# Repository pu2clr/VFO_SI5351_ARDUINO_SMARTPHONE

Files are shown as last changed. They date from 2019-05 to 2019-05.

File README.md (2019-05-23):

# VFO and BFO using Arduino with Si5351 controlled by SmartPhone

By PU2CLR - Ricardo Lima Caratti  - April, 2019

## Table of contents

1. [Introduction](https://github.com/pu2clr/VFO_SI5351_ARDUINO_SMARTPHONE#introduction)
2. [VFO and BFO Interface](https://github.com/pu2clr/VFO_SI5351_ARDUINO_SMARTPHONE#vfo-and-bfo-interface)
3. [Schematic used with Arduino Atmega328 (UNO, Pro Mini, Nano etc)](https://github.com/pu2clr/VFO_SI5351_ARDUINO_SMARTPHONE#schematic---arduino-atmega328-uno-pro-mini-nano-etc)
4. [Arduino Sketch](https://github.com/pu2clr/VFO_SI5351_ARDUINO_SMARTPHONE#arduino-sketch)
   1. [Band Table](https://github.com/pu2clr/VFO_SI5351_ARDUINO_SMARTPHONE#band-table) 
   2. [Step Table](https://github.com/pu2clr/VFO_SI5351_ARDUINO_SMARTPHONE#step-table)
   3. [Callback Functions](https://github.com/pu2clr/VFO_SI5351_ARDUINO_SMARTPHONE#callback-functions)
5. [Mobile Application](https://github.com/pu2clr/VFO_SI5351_ARDUINO_SMARTPHONE#mobile-application)
6. [Videos](https://github.com/pu2clr/VFO_SI5351_ARDUINO_SMARTPHONE#videos)

## Introduction

This project implements a VFO and BFO  using an Arduino with Si5351 signal generator. You can controll the VFO using an encoder and also a SmartPhone via a mobile application developed here for this purpose. 

The heart of this VFO is the component Si5351. It is an I2C configurable clock generator that is very appropriate for receivers and transceivers projects in amateur radio applications. It has three outputs that you can get three distinct frequencies at the same time. A great feature of the Si5351A is the possibility of using it with a microcontroller or platform like Arduino, PIC family and others. See more on [Silicon Labs documentation](https://www.silabs.com/documents/public/data-sheets/Si5351-B.pdf).

 This project uses two outputs of the Si5351.  The VFO  uses the output 0 (CLK0) and can oscillate from 100KHz to 160MHz. The BFO uses the output 1 (CLK1) of Si5351 and it was configured to oscillate from 452KHz to 458KHz (you can modigy the BFO range to any other from 8KHz to 160MHz).  

 The Arduino sketch was projected to allow the user modify easly the band, range and step configurations.
 See Arduino Sketch below. 

## VFO and BFO interface

The user can control the VFO and BFO by using three buttons (bands, steps and VFO / BFO switch) and an encoder. The user can also connect this VFO with an iOS or Android device and control it remotelly.  The Dial was implemented with the OLED Display 128 x 64 Pixels White 0.96 Inch I2C. 

### Display Layout

| Layout |  Layout |
| --- |  --- |
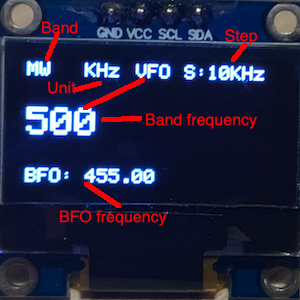
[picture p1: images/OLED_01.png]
Display photo 1
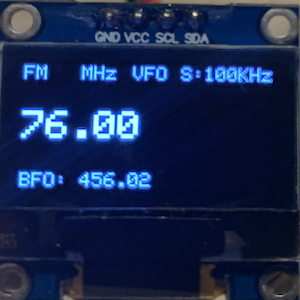
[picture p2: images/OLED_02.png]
Displau photo 2
| |  |
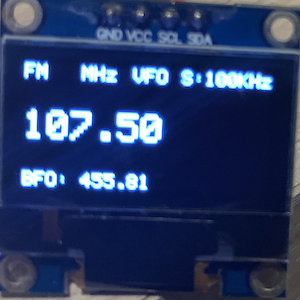
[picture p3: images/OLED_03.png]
Display photo 3
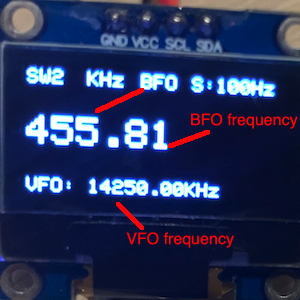
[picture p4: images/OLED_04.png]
Displau photo 4
| |  |

The display layout can be modified easily by changing the __DialDisplay() function__ on Arduino sketch. 

### Simple Smartphone Layout

| iPhone Application | Android Application  | 
| --- | --- |
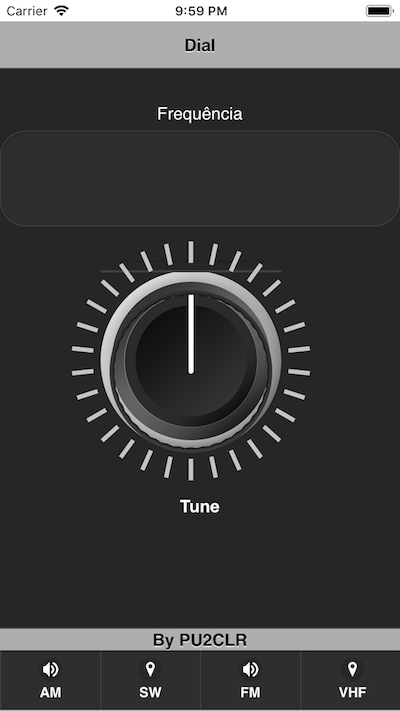
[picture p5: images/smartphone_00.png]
Smartphone Layout - iPhone
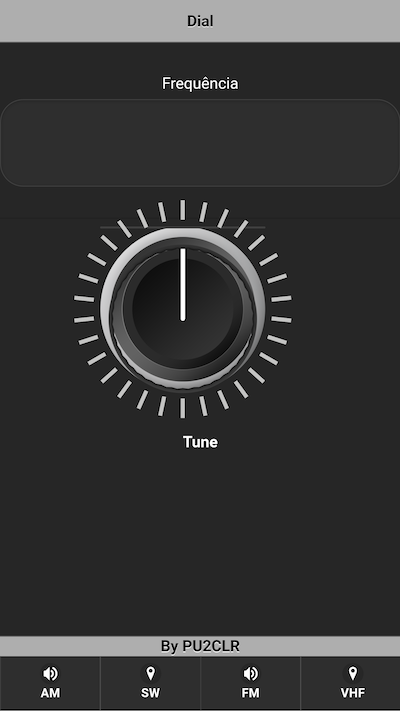
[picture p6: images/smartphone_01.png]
Smartphone Layout - iPhone
|  |  | 
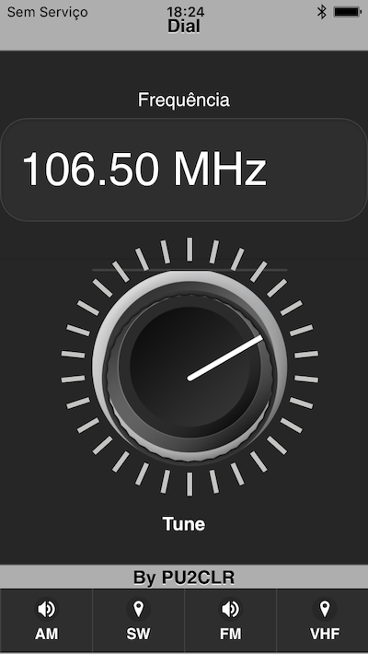
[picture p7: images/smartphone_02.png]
Smartphone Layout - iPhone
|  | - | 

See more detail about the [Mobile Application](https://github.com/pu2clr/VFO_SI5351_ARDUINO_SMARTPHONE#mobile-application) below.

## Schematic - Arduino Atmega328 (UNO, Pro Mini, Nano etc)

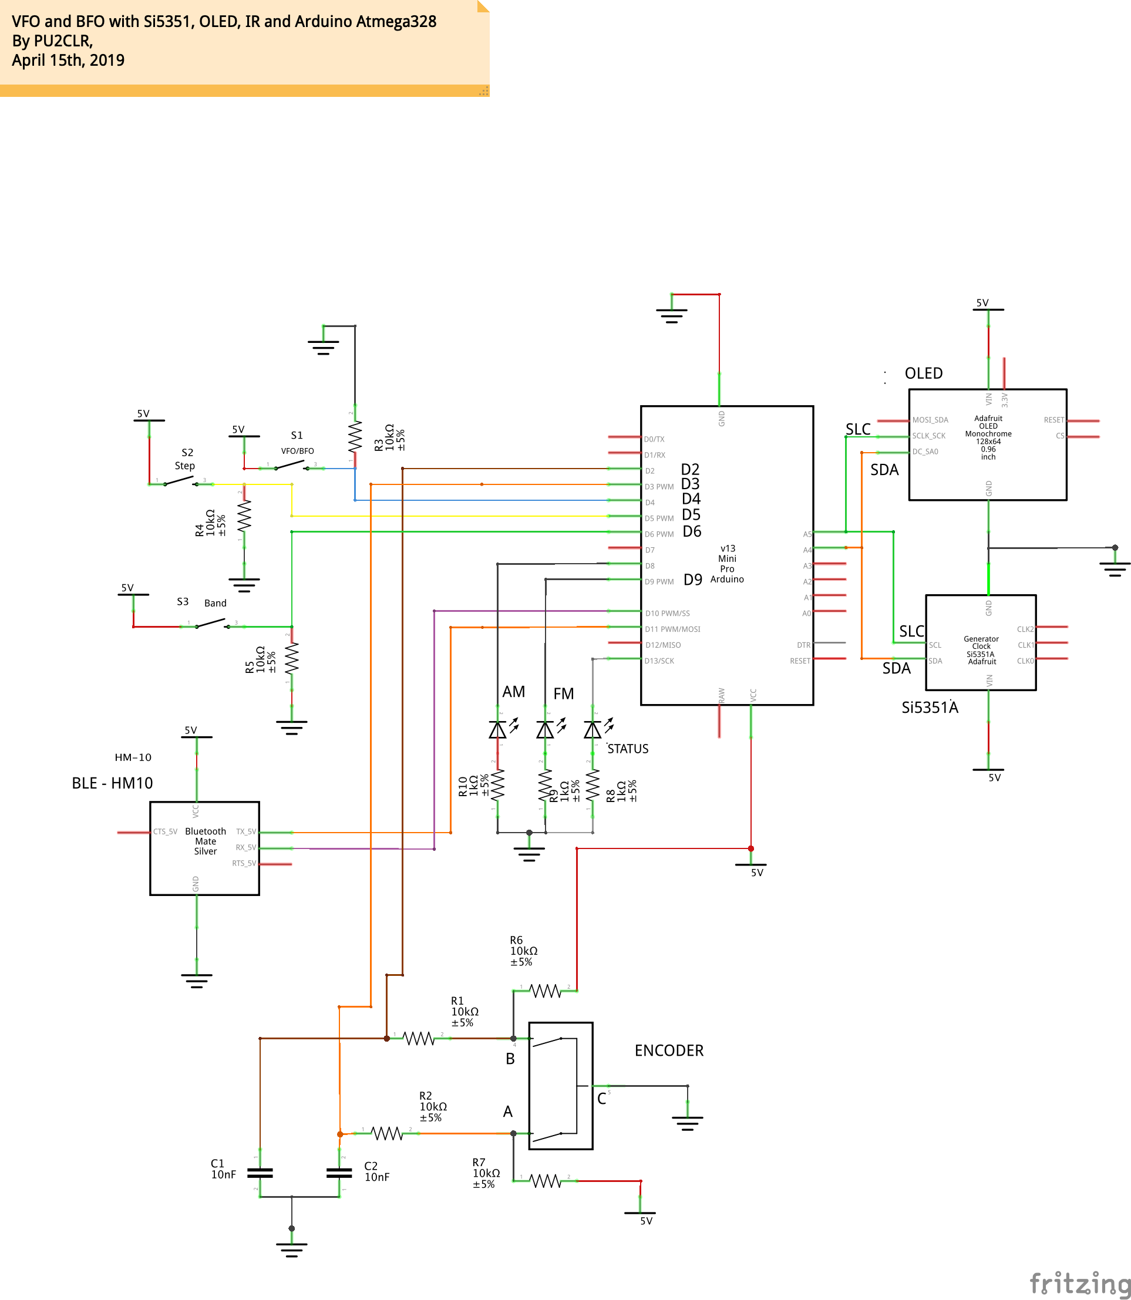
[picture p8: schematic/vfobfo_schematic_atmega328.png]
Schematic used with Arduino Atmega328


## Arduino Sketch 

The VFO and BFO project cen be easily modified to adapt it better to your needs. 
The main feature of the Sketch is the table of band. You can modify the amount of bands and ranges. The band information is shown below. 
 
| Band Information | Desription | 
| --- | --- |
| __Band name__ | Band name that will show on display. |
| __Initial Freq.__ |  Lowest band frequency (1/100 Hz). |
| __Final Freq.__ | highest frequency band (1/100 Hz). |
| __Last Freq.__ | Store the current frequency. Useful when the user switches the band and get back to it later (it starts with minFreq value). |
| __offset__ | Consider an IF offset.  The VFO shows on the display the real frequency of the station and makes the signal generator to oscillate considering the IF used by the radio design (1/100 Hz). |
| __Freq Unit__ | Frequency unit that will be shown on the display for the current band. |
| __Divider__ | Divider used to reduce the number of digits in the display. |
| __decimals__ | number of decimal places (precision). |
| __Initial Step Index__ | Lowest step index used for the band (see Step table). |
| __Final Step Index__ | Highest step index used for the band (see Step table). | 
| __Last Step Index__ | Default step index or last step index used for the band (see Step table). Useful when the user gets back to a band. | 
| __callback function__ | Pointer to the function that handles something when the band is selected. Can be NULL if there is nothing to do.  |

The implementation of the band information is shown below.  An array of band structure information is implemmented 

```cpp
// Structure for Bands database
typedef struct
{
  char *name;
  uint64_t minFreq;       // Min. frequency value for the band (unit 0.01Hz)
  uint64_t maxFreq;       // Max. frequency value for the band (unit 0.01Hz)
  uint64_t lastFreq;      // Store the current frequency before change to other band (starts with minFreq value)
  long long offset;
  char *unitFreq;         // MHz or KHz
  float divider;          // value that will be the divider of current clock (just to present on display)
  short decimals;         // number of digits after the comma
  short initialStepIndex; // Index to the initial step of incrementing
  short finalStepIndex;   // Index to the final step of incrementing
  short lastStepIndex;    // Index to the last step used (initial index value same index defult)
  void (*doSmth)(void);   // pointer to the function that will handle specific things for the band immediately after the band is selected
 } Band;
```

The code below implements the band table (array) of the VFO for a hypothetical radio. 
The hypothetical radio used as an example here has 10 bands. Each band has a frequency range, a default frequency, an IF offset, a unit used for the band (MHz or KHz), a divider to convert the unit (from 1/100Hz to KHz or MHz), decimal digits used for the band (precision), minimum step used for the band (index), maximum step used for the band, default step index and a pointer to function that will be executed when the band is selected (or NULL if no action is needed).  The values amBroadcast, fmBroadcast and defultFinishBand are pointers to functions that will execute some specific actions for the band. When the value is NULL, no action will be executed.  You might need change these values depending on your radio design. 

```cpp
// Band database. You can change the band ranges if you need.
// The unit of frequency here is 0.01Hz (1/100 Hz). See Etherkit Library at https://github.com/etherkit/Si5351Arduino
 Band band[] = {
     {"MW  ", 50000000LLU, 170000000LLU, 50000000LLU, 45500000LU, "KHz", 100000.0f, 0, 3, 6, 5, amBroadcast},
     {"SW1 ", 170000000LLU, 1000000000LLU, 170000000LLU, 45500000LU, "KHz", 100000.0f, 2, 1, 6, 3, amBroadcast},
     {"SW2 ", 1000000000LLU, 2000000000LLU, 1000000000LLU, 45500000LU, "KHz", 100000.0f, 2, 1, 6, 3, amBroadcast},
     {"SW3 ", 2000000000LLU, 3000000000LLU, 2000000000LLU, 45500000LU, "KHz", 100000.0f, 2, 1, 6, 3, amBroadcast},
     {"VHF1", 3000000000LLU, 7600000000LLU, 3000000000LLU, 45500000LU, "KHz", 100000.0f, 2, 1, 7, 3, defultFinishBand},
     {"FM  ", 8600000000LLU, 10800000000LLU, 8600000000LLU, 1075000000LLU, "MHz", 100000000.0f, 2, 5, 8, 7, fmBroadcast},
     {"AIR ", 10800000000LLU, 13700000000LLU, 10800000000LLU, 1070000000LLU, "MHz", 100000000.0f, 3, 2, 8, 5, NULL},
     {"VHF2", 13700000000LLU, 14400000000LLU, 13700000000LLU, 1070000000LLU, "MHz", 100000000.0f, 3, 2, 8, 5, defultFinishBand},
     {"2M  ", 14400000000LLU, 15000000000LLU, 14400000000LLU, 1070000000LLU, "MHz", 100000000.0f, 3, 2, 8, 5, defultFinishBand},
     {"VFH3", 15000000000LLU, 16000000000LLU, 15000000000LLU, 1070000000LLU, "MHz", 100000000.0f, 3, 2, 8, 5, defultFinishBand}};
 // Calculate the last element position (index) of the array band
```

### Band Table 

The table of bands implemented above for the hypothetical radio can be seen below. The values of Initial Step Index, Final Step Index and Default/Last Step index can be got from the Step table.  

| Band name | Initial Freq.  | Final Freq. | Last Freq. | offset | Freq Unit | Divider | Dec. | Initial Step Index | Final Step Index | Default / Last Step index | Action Function |
| --- | --- | --- | --- | --- | ---| --- |--- | --- | --- | ---| ---|
| MW | 50000000 | 170000000 | 50000000 | 45500000 |  KHz | 100000 | 2 | 3 | 6 | 5 | amBroadcast |
| SW1  | 170000000 | 1000000000 | 170000000 | 45500000  | KHz | 100000 | 2 | 2 | 6 | 3 | amBroadcast |
| SW2  | 1000000000 | 2000000000 | 1000000000 | 45500000  | KHz | 100000 | 2 | 2 | 6 | 3 | amBroadcast |
| SW3  | 2000000000 | 3000000000 | 2000000000 | 45500000  | KHz | 100000 | 2 | 2 | 6 | 3 | amBroadcast |
| VHF1 | 3000000000 | 7600000000 | 3000000000 | 45500000  | KHz | 100000 | 2 | 2 | 7 | 3 | defultFinishBand |
| FM | 7600000000 | 10800000000 | 7600000000 | 1075000000  | MHz |  100000000 | 1 | 6 | 8 | 7 | fmBroadcast |
| AIR  | 10800000000 | 13700000000 | 10800000000 | 1075000000  | MHz | 100000000 | 2 | 2 | 8 | 5 | NULL |
| VHF2 | 13700000000 | 14400000000 | 13700000000 | 1075000000  | MHz | 100000000 | 2 | 2 | 8 | 5 | defultFinishBand |
| 2M  | 14400000000 | 15000000000 | 14400000000 | 1075000000  | MHz | 100000000 | 2 | 2 | 8 | 5 | defultFinishBand |
| VFH3 | 15000000000 | 16000000000 | 15000000000 | 1075000000  | MHz| 100000000 | 2 | 2 | 8| 5 | defultFinishBand |

### Step Table 

Each band uses a subset of the table of steps. It will depend on the characteristics of the band. For example: usually, 5KHz and 10 KHz are more apropriated to MW band. Working on SW bands, you might want 1KHz, 5KHz and 10KHz. The step table is implemented by the code below.  

```cpp
// Struct for step database
typedef struct
{
  char *name; // step label: 50Hz, 100Hz, 500Hz, 1KHz, 5KHz, 10KHz and 500KHz
  long value; // Frequency value (unit 0.01Hz See documentation) to increment or decrement
} Step;
```

The code beloow implements an array of steps (Steps)

```cpp 
// Steps database. You can change the Steps and numbers of steps here if you need.
Step step[] = {
    {"10Hz  ", 1000},
    {"100Hz ", 10000},
    {"500Hz ", 50000},
    {"1KHz  ", 100000},
    {"5KHz  ", 500000},
    {"10KHz  ",1000000},
    {"50KHz ", 5000000},
    {"100KHz", 10000000},
    {"500KHz", 50000000}};
```

The table of steps implemented above  can be seen below.

| Step Index | Step name | Step Value (1/100 Hz) |
| --- | --- | --- |
| 0 | 10Hz | 1000 |
| 1 | 100Hz | 10000 |
| 2 | 500Hz | 50000 |
| 3 | 1KHz | 100000 |
| 4 | 5KHz | 500000 |
| 5 | 10KHz |  1000000 |
| 6 | 50KHz |  5000000 |
| 7 | 100KHz | 10000000 |
| 8 | 500KHz | 50000000 |

### Callback functions

This sketch uses callback functions to complement specific actions for a specific band. 
For example, you might need to turn a LED on, start a relay or set up a filter when you select a particular band.  If the device that will use this VFO/BFO has different behaviours for different band, you might want to use callback functions.  If you do not need to use this features, you can set this data (parameter) with NULL in table of bands. See Band table for more information. 

The code below shows the callback functions declaration

```cpp
// Callback functions declarations
// Depending on the selected band, you may want to perform specific actions
// The functions declared below will do something for AM and FM BAND. See implementation later.
// You can implement callback function for other bands
void amBroadcast();      // See implementation later.
void fmBroadcast();      // See implementation later.
void defultFinishBand(); // 
```

The callback functions above are referenced in band database (see table of bands -  array band[]) above.

```cpp
// Callback implementation

// Doing something spefict for MW band
void amBroadcast()
{
  digitalWrite(AM_LED, HIGH); // Turn ON the AM LED
  digitalWrite(FM_LED, LOW);
  // DO SOMETHING ELSE
}

// Doing something spefict for FM
void fmBroadcast()
{
  digitalWrite(AM_LED, LOW);
  digitalWrite(FM_LED, HIGH); // Turn ON the FM LED
  // DO SOMETHING ELSE
}

// Defaul action 
// It is another callback function that can be called when a specific band is selected 
void defultFinishBand()
{
  digitalWrite(FM_LED, LOW); // Turno the FM LED OFF
  digitalWrite(AM_LED, LOW); // Turno the AM LED OFF
  // DO SOMETHING ELSE  
}

```

The code below shows the use of callback function when the use changes the band

```cpp
// It is executed when a new band is selected.
void changeBand(short idxBand)
{
  // Save current status of the current band
  band[currentBand].lastStepIndex = currentStep;
  band[currentBand].lastFreq = vfoFreq;

  // Now change the current band  
  currentBand = idxBand;

  // Get back last information stored for this band.
  vfoFreq = band[idxBand].lastFreq;           
  currentStep = band[idxBand].lastStepIndex;

  // Call callback function if exist something to do for this band (current band)
  if (band[idxBand].doSmth != NULL)
    (band[idxBand].doSmth)();

  isFreqChanged = true;
}
```  

The complete Arduino Sketch can be seen [here](https://github.com/pu2clr/VFO_SI5351_ARDUINO_SMARTPHONE/tree/master/source)

## Mobile Application

The reduced length of the Oled display might limit some VFO functionalities.  The goal of this mobile application is improve the VFO control and visualization. 

### Bluetooth BLE (HM10 - HMSOft TineSine)

The Bluetooth 4.0 used here is the HM10 (TinySine). It is very similar to the famous HC-05. The photos below show the HM10 Bluetooth.
This kind of Bluetooth works well on iOs and Android based device.

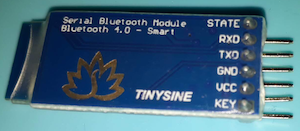
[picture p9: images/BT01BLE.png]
HM10 - HMSOft TineSine 01


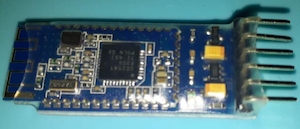
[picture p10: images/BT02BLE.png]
HM10 - HMSOft TineSine 02


#### HM10 Documentation

* [HM-10 Bluetooth 4 BLE Modules - Martyn Currey](http://www.martyncurrey.com/hm-10-bluetooth-4ble-modules/)
* [BLE CENTRAL - HM-10 BLE Module](http://blog.blecentral.com/2015/05/05/hm-10-peripheral/)

### Compile and deploy this mobile application

Please copy the project to a local folder and follow the steps bellow

You have to install [Android Studio](http://developer.android.com/sdk/index.html) on your computer to compile and deploy this application on your Android.

You have to install [Xcode](https://developer.apple.com/xcode/) on your Mac computer to compile and deploy this application on your iPhone or iPad.  

### Pairing your phone

You have to pair your Android phone with the HM10 Bluetooth Shield.

### Cordova 

This applications was build using the [Apache Cordova](https://cordova.apache.org/docs/en/latest/guide/overview/index.html). 
[Apache Cordova](https://cordova.apache.org/docs/en/latest/guide/overview/index.html) is an open-source tool to develop cross-platform mobile application. Click [here](https://cordova.apache.org/docs/en/latest/guide/overview/index.html) to see more about Apache Cordova.

### Install Cordova

    $ npm install cordova -g

### Install Platform and Plugin

    $ cordova platform add android
    $ cordova platform add ios
    $ cordova plugin add cordova-plugin-bluetooth-serial

#### cordova-plugin-bluetooth-serial information

* [Bluetooth Serial Plugin for PhoneGap](https://www.npmjs.com/package/cordova-plugin-bluetooth-serial)
* [Bluetooth Serial Plugin for PhoneGap - github](https://github.com/don/BluetoothSerial)

### Build and Deploy

Compile and run the application

    $ cordova run android --device

## Videos 

- [VFO and BFO project test with an inexpencive radio based on CD2003GP](https://youtu.be/_KgBc6vYWLg)
- [Testing the VFO with a CD2003GM HOMEBREW FM RECEIVER](https://youtu.be/JfgRjDK8LTE)
- [VFO and BFO remote control with iPhone via Bluetooth](https://youtu.be/7gBRUmsrCus)

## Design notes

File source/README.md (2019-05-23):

# Sorce content

By PU2CLR - Ricardo Lima Caratti  - April, 2019

| Folder name | Description | 
| --- | --- |
| si5351_vfo_ble_atmega328  | Arduino Sketch for Atmega328 (Uno, Nano, Mini etc) | 
| si5351_vfo_ble_atmega328X | Arduino Sketch for Atmega328 (Uno, Nano, Mini etc) with Ben Buxton Encoder implementation | 
| vfoMobileApplication | iOs and Android remote control implementation for the VFO |

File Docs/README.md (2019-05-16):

# Testando o VO e BFO em um rádio barato baseado no chip CD2003GP 

__Importante: Documentação ainda em construção__

Por PU2CLR - Ricardo
April, 2019

## Sumário

1. [Introdução](https://github.com/pu2clr/VFO_BFO_OLED_ARDUINO/tree/master/Experiments/VFO_RADIO_CD2003GP/Docs#introdução)
2. [Apresentação do Display](https://github.com/pu2clr/VFO_BFO_OLED_ARDUINO/tree/master/Experiments/VFO_RADIO_CD2003GP/Docs#apresentação-do-display)
3. [Esquema para Arduino baseado no Atmega328 (UNO, Pro Mini, Nano etc)](https://github.com/pu2clr/VFO_BFO_OLED_ARDUINO/tree/master/Experiments/VFO_RADIO_CD2003GP/Docs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)
4. [Esquema para Arduino baseado ATmega32U4 (Micro)](https://github.com/pu2clr/VFO_BFO_OLED_ARDUINO/tree/master/Experiments/VFO_RADIO_CD2003GP/Docs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)
5. [O Rádio baseado no CD2003GP utilizado no teste](https://github.com/pu2clr/VFO_BFO_OLED_ARDUINO/tree/master/Experiments/VFO_RADIO_CD2003GP/Docs#o-rádio-baseado-no-cd2003gp-utilizado-no-teste)
   1. [Diagrama de Bloco do CD2003GP](https://github.com/pu2clr/VFO_BFO_OLED_ARDUINO/tree/master/Experiments/VFO_RADIO_CD2003GP/Docs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)
   2. [Circúito de Aplicação](https://github.com/pu2clr/VFO_BFO_OLED_ARDUINO/tree/master/Experiments/VFO_RADIO_CD2003GP/Docs#circúito-de-aplicação)
   3. [Foto do Rádio](https://github.com/pu2clr/VFO_BFO_OLED_ARDUINO/tree/master/Experiments/VFO_RADIO_CD2003GP/Docs#foto-do-rádio)
   4. [Modificação no estágio de FM](https://github.com/pu2clr/VFO_BFO_OLED_ARDUINO/tree/master/Experiments/VFO_RADIO_CD2003GP/Docs#modificação-no-estágio-de-fm)
   5. [Acoplamento do si5351 no pino 13 do CD2003GP](https://github.com/pu2clr/VFO_BFO_OLED_ARDUINO/tree/master/Experiments/VFO_RADIO_CD2003GP/Docs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)
   6. [Sugestões para acoplamento](https://github.com/pu2clr/VFO_BFO_OLED_ARDUINO/tree/master/Experiments/VFO_RADIO_CD2003GP/Docs#sugestões-para-acoplamento)
6. [Arduino Sketch](https://github.com/pu2clr/VFO_BFO_OLED_ARDUINO/tree/master/Experiments/VFO_RADIO_CD2003GP/Docs#arduino-sketch)
   1. [Tabela de Bandas](https://github.com/pu2clr/VFO_BFO_OLED_ARDUINO/tree/master/Experiments/VFO_RADIO_CD2003GP/Docs#band-table)
   2. [Tabela de passos](https://github.com/pu2clr/VFO_BFO_OLED_ARDUINO/tree/master/Experiments/VFO_RADIO_CD2003GP/Docs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)
   3. [Função no estilo callback](https://github.com/pu2clr/VFO_BFO_OLED_ARDUINO/tree/master/Experiments/VFO_RADIO_CD2003GP/Docs#funções-no-estilo-callback)
   4. [Explicando o uso de sizeof](https://github.com/pu2clr/VFO_BFO_OLED_ARDUINO/tree/master/Experiments/VFO_RADIO_CD2003GP/Docs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)
   5. [Explicando as estruturas Band e Step](https://github.com/pu2clr/VFO_BFO_OLED_ARDUINO/tree/master/Experiments/VFO_RADIO_CD2003GP/Docs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)
   6. [Explicando como o Encoder está codificado](https://github.com/pu2clr/VFO_BFO_OLED_ARDUINO/tree/master/Experiments/VFO_RADIO_CD2003GP/Docs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á-codificado)
7. [Source folder](https://github.com/pu2clr/VFO_BFO_OLED_ARDUINO/tree/master/Experiments/VFO_RADIO_CD2003GP/source)
   1. [Arduino sketch para Atmega328 - si5351_vfoCD2003GP_atmega328.ino](https://github.com/pu2clr/VFO_BFO_OLED_ARDUINO/tree/master/Experiments/VFO_RADIO_CD2003GP/source/si5351_vfoCD2003GP_atmega328)
   2. [Arduino sketch para Atmega32U4 - si5351_vfoCD2003GP_atmega32u4.ino](https://github.com/pu2clr/VFO_BFO_OLED_ARDUINO/tree/master/Experiments/VFO_RADIO_CD2003GP/source/si5351_vfoCD2003GP_atmega32u4) 
   3. [Arduino sketch Atmega328 e Bluetooth BLE-HM10 - si5351_vfo_ble_atmega328.ino](https://github.com/pu2clr/VFO_BFO_OLED_ARDUINO/tree/master/Experiments/VFO_RADIO_CD2003GP/source/si5351_vfo_ble_atmega328)
   4. [Aplicativo para Celular Android e iOS para controlar o VFO](https://github.com/pu2clr/VFO_BFO_OLED_ARDUINO/tree/master/Experiments/VFO_RADIO_CD2003GP/source/vfoMobileApplication)
8.  [Vídeos](https://github.com/pu2clr/VFO_BFO_OLED_ARDUINO/tree/master/Experiments/VFO_RADIO_CD2003GP/Docs#v%C3%ADdeos)

## Introdução

Este teste modifica o sketch do Arduino original e apresenta duas versões. Há duas versões do sketch, uma para Arduino baseado no Atmega328 e outra para o Atmega32U4. 
O rádio utilizado neste teste é um CMik KK9, baseado no chip CD2003GP ou TA2003. Este rádio foi escolhido pela baixo custo de aquisição ( aproximadamente R$30,00). Trata-se de um receptor de Ondas Médias, Ondas Curtas e FM. Em MW e SW o rádio tem péssima seletividade. Contudo, a escuta de estações locais de AM é possível. Em FM o rádio se comporta um pouco melhor. 

Principais mudanças no sketch do Arduino

- Apresentação do Display 
- Quantidade reduzida de Bandas. Veja a [Tabela de Bandas a seguir]()
- Cada banda tem um comportamento diferente. Passos mais apropriados ee ações podem ser diferentes para bandas diferentes. 
- That is, frequency unit shown on the display and steps more suitable for the specific band. 

## Apresentação do Display

| Layout |  Layout |
| --- |  --- |
| Displau photo 1| Displau photo 2 |
| Displau photo 3| Displau photo 4 |

## Esquema para Arduino baseado no Atmega328 (UNO, Pro Mini, Nano etc)

Schematic used with Arduino Atmega328

__Click [here](https://github.com/pu2clr/VFO_BFO_OLED_ARDUINO/blob/master/Experiments/VFO_RADIO_CD2003GP/source/si5351_vfoCD2003GP_atmega328/si5351_vfoCD2003GP_atmega328.ino) to see the sketch used on Arduino Atmega328 (schematic above).__

## Esquema para Arduino baseado ATmega32U4 (Micro)

Schematic used with Arduino Atmega328

__Click [here](https://github.com/pu2clr/VFO_BFO_OLED_ARDUINO/blob/master/Experiments/VFO_RADIO_CD2003GP/source/si5351_vfoCD2003GP_atmega32u4/si5351_vfoCD2003GP_atmega32u4.ino) to see the sketch used on Arduino ATmega32U4 (schematic above).__ 

## O Rádio baseado no CD2003GP utilizado no teste

### Diagrama de Bloco do CD2003GP 

Photo 1 - CD2003GP

[Source - CD2003GP Datasheet](http://www.datasheetcafe.com/cd2003gp-datasheet-pdf/)

### Circúito de Aplicação

Photo 2 - CD2003GP

[Source - CD2003GP Datasheet](http://www.datasheetcafe.com/cd2003gp-datasheet-pdf/)

### Foto do Rádio
Photo 3 - Inexpensive commercial radio

### Modificação no estágio de FM

Este experimento foi baseado 

No primeiro teste foi isolado o pino 13 do chip CD2003GP e injetado o sinal da saída 0 do si5351 (CLK0). Para conectar essa saída no pino 13 foi utilizado o próprio capacitor de 15Pf que acopla o oscilador do próprio rádio. 

Photo 3 - Motification

#### Acomplamento do si5251 no pino 13 do si5351 

Photo 2 - CD2003GP

Photo 3 - Motification

#### Sugestões para acoplamento

No primeiro teste, a perna do capacitor de 15Pf que acopla o oscilador local ao pino 13 do CD2003GP foi dessolada, ficando o capacitor e o pino 13 isolado do rádio.  Assim, a perna dessoldada foi conectada à  ao VFO (saída do si5351 - CLK0). 

Coupling 01

Coupling 02

Coupling 03

## Arduino Sketch 

Esta seção apresenta alguns aspectos da programação do VFO e BFO.  É importante ressaltar que alguns recursos previstos neste sketch podem não ser implementados no rádio usado como exemplo. 

O centro das informações do VFO está armazenado em uma tabela seguintes informações para cada banda:  

| Atributo |  Descrição |  Variável | 
| --- | --- | --- |
| Nome da Banda | Nome da Banda que será apresentada no Display | *name |
| Freq. Inicial | Freqência inicial da Banda (1/100 Hz) | minFreq |
| Freq. Final | Freqência final (1/100 Hz) | maxFreq | 
| Deslocamento  | Deslocamento em 1/100Hz utilizado na banda para compensar a FI (1/100 Hz) | offset |
| Unidade | Unidade de freqência utilizada na Banda | *unitFreq |
| Divisor | Divisor usado para expressar a freqência utilizada na banda | divider | 
| Casas Decimais| Número de casas decimais depois da vírgula utilizada para a banda | decimals |
| Menor passo | Índice para o menor passo utilizado na banda (ver tabela de passos) | finalStepIndex | 
| Maior passo | Índice do maior passo utilizado na banda | finalStepIndex |
| Passo Padrão  | Índice do passo padrão da banda | starStepIndex |
| Função de chamada | Função que será executada quando uma banda for selecionada | *f |

A representação em C para as informações de uma banda no tipo definido __Band__.

```cpp
// Structure for Bands database
typedef struct
{
  char *name;
  uint64_t minFreq; // Min. frequency value for the band (unit 0.01Hz)
  uint64_t maxFreq; // Max. frequency value for the band (unit 0.01Hz)
  long long offset;
  char *unitFreq;         // MHz or KHz
  float divider;          // value that will be the divider of current clock (just to present on display)
  short decimals;         // number of digits after the comma
  short initialStepIndex; // Index to the initial step of incrementing
  short finalStepIndex;   // Index to the final step of incrementing
  short starStepIndex;    // Default Index for the band
  void (*f)(void);        // pointer to the function that handles specific things for the band
} Band;
```

### Tabela de Bandas

Um array da estrutura __Band__ é criado para representar todo o conjunto de bandas que serão trabalhadas no VFO. 

| Band name | Initial Freq.  | Final Freq. | offset | Freq Unit | Divider | Dec. | Initial Step Index | Final Step Index | Default |
| --- | --- | --- | --- | ---| --- |--- | --- | --- | ---|
| MW | 50000000 | 170000000 | 45500000 |  KHz | 100000 | 2 | 3 | 6 | 5 |
| SW1  | 170000000 | 1000000000 | 45500000  | KHz | 100000 | 2 | 2 | 6 | 3 |
| SW2  | 1000000000 | 2000000000 | 45500000  | KHz | 100000 | 2 | 2 | 6 | 3 |
| SW3  | 2000000000 | 3000000000 | 45500000  | KHz | 100000 | 2 | 2 | 6 | 3 |
| VHF1 | 3000000000 | 7600000000 | 45500000  | KHz | 100000 | 2 | 2 | 7 | 3 |
| FM | 7600000000 | 10800000000 | 1075000000  | MHz |  100000000 | 1 | 6 | 8 | 7 |
| AIR  | 10800000000 | 13700000000 | 1075000000  | MHz | 100000000 | 2 | 2 | 8 | 5 |
| VHF2 | 13700000000 | 14400000000 | 1075000000  | MHz | 100000000 | 2 | 2 | 8 | 5 |
| 2M  | 14400000000 | 15000000000 | 1075000000  | MHz | 100000000 | 2 | 2 | 8 | 5 |
| VFH3 | 15000000000 | 16000000000 | 1075000000  | MHz| 100000000 | 2 | 2 | 8| 5 |

O código a seguir implementa a tabela de banda para do VFO. 
O campo contendo __amBroadcast__, __fmBroadcast__ ou __NULL__ são referências para funções que executarão algumas ações específicas para a banda tão logo a banda seja selecionada. Quando a referência for __NULL__ para a banda, nenhuma função será executada. 

```cpp
// Band database. You can change the band ranges if you need.
// The unit of frequency here is 0.01Hz (1/100 Hz). See Etherkit Library at https://github.com/etherkit/Si5351Arduino
Band band[] = {
    {"MW  ", 50000000LLU, 170000000LLU, 45500000LU, "KHz", 100000.0f, 0, 3, 6, 5, amBroadcast},
    {"SW1 ", 170000000LLU, 1000000000LLU, 45500000LU, "KHz", 100000.0f, 2, 1, 6, 3, amBroadcast},
    {"SW2 ", 1000000000LLU, 2000000000LLU, 45500000LU, "KHz", 100000.0f, 2, 1, 6, 3, amBroadcast},
    {"SW3 ", 2000000000LLU, 3000000000LLU, 45500000LU, "KHz", 100000.0f, 2, 1, 6, 3, amBroadcast},
    {"VHF1", 3000000000LLU, 7600000000LLU, 45500000LU, "KHz", 100000.0f, 2, 1, 7, 3, NULL},
    {"FM  ", 7600000000LLU, 10800000000LLU, 1075000000LLU, "MHz", 100000000.0f, 2, 6, 8, 7, fmBroadcast},
    {"AIR ", 10800000000LLU, 13700000000LLU, 1075000000LLU, "MHz", 100000000.0f, 3, 2, 8, 5, NULL},
    {"VHF2", 13700000000LLU, 14400000000LLU, 1075000000LLU, "MHz", 100000000.0f, 3, 2, 8, 5, NULL},
    {"2M  ", 14400000000LLU, 15000000000LLU, 1075000000LLU, "MHz", 100000000.0f, 3, 2, 8, 5, NULL},
    {"VFH3", 15000000000LLU, 16000000000LLU, 1075000000LLU, "MHz", 100000000.0f, 3, 2, 8, 5, NULL}};
```

### Tabela de Passos

A tabela de passos foi implementada com um array de estrutura conforme mostrado a seguir. É importante ressaltar que cada pbanda usar somente um subconjunto de passos contidos na tabela. Este subconjunto está definido na tabela de bandas (band[]).

```cpp
// Struct for step database
typedef struct
{
  char *name; // step label: 50Hz, 100Hz, 500Hz, 1KHz, 5KHz, 10KHz and 500KHz
  long value; // Frequency value (unit 0.01Hz See documentation) to increment or decrement
} Step;
```

```cpp 
// Steps database. You can change the Steps and numbers of steps here if you need.
Step step[] = {
    {"10Hz  ", 1000},
    {"100Hz ", 10000},
    {"500Hz ", 50000},
    {"1KHz  ", 100000},
    {"5KHz  ", 500000},
    {"10KHz  ",1000000},
    {"50KHz ", 5000000},
    {"100KHz", 10000000},
    {"500KHz", 50000000}};
```

Os atributos __initialStepIndex__, __finalStepIndex__ e  __starStepIndex__, armazenam os índices do array __step[]__.    

| Step Index | Step name | Step Value (1/100 Hz) |
| --- | --- | --- |
| 0 | 10Hz | 1000 |
| 1 | 100Hz | 10000 |
| 2 | 500Hz | 50000 |
| 3 | 1KHz | 100000 |
| 4 | 5KHz | 500000 |
| 5 | 10KHz |  1000000 |
| 6 | 50KHz |  5000000 |
| 7 | 100KHz | 10000000 |
| 8 | 500KHz | 50000000 |

### Funções no estilo callback

As tabelas anteriores buscam oferecer dados sobre cada banda de tal forma que o processamento levará em consideração esses dados para realizar ações pertinentes a banda em uso. No entanto, para desempenhar ações de mais baixo nível, optou-se por utilizar funções no estilo "callback". Uma chamada callback é um recurso muito utilizado onde uma função é passada como argumento para outra função poder executá-la. No nosso exemplo, as funções no estilo "callback" não são enviadas como parâmetros. Na realidade, a tabela de bandas possui referências para funções que deverá ser chamada para complementar alguma ação específica para a banda em uso. Por exemplo, para acionar AM no rádio baseado no CD2003GP, é necessário colocar o pino 14 do chip em nível lógico baixo. Em contrapartida, para acionar FM no rádio, é necessário que o pino 14 do CD2003GP esteja em nível lógico alto. 
Se nenhuma ação precisa ser executada para a banda específica, o valor NULO (NULL) é atribuído à informação. 

O código a seguir ilustra a utilização da funções no estilo "callback".

```cpp
// Callback functions declarations
// Depending on the selected band, you may want to perform specific actions
// The functions declared below will do something for AM and FM BAND. See implementation later.
// You can implement callback function for other bands
void amBroadcast(); // See implementation later.
void fmBroadcast(); // See implementation later.
```
As funções declaradas anteriormente são referênciadas na estrutura de bandas (veja o array band[]).

```cpp
// Callback implementation

// Doing something spefict for AM
// Example: set Pin 14 of the CD2003GP to LOW; switch filter, turn AM LED on etc
void amBroadcast()
{
  // TO DO
  STATUSLED(HIGH); // Just testing if it is working - Turn LED ON
}

// Doing something spefict for FM
// Example: set Pin 14 of the CD2003GP to HIGH; turn FM LED on etc
void fmBroadcast()
{
  // TO DO
  STATUSLED(LOW); // Just testing if it is working - Turn LED OFF
}
```

Note no código a seguir que se a banda possuir uma função no estilo "callback" (diferente de nulo - band[currentBand].f != NULL), então a função é executada. 

```cpp
 if (digitalRead(BUTTON_BAND) == HIGH && (millis() - elapsedButton) > MIN_ELAPSED_TIME)
  {
    currentBand = (currentBand < lastBand) ? (currentBand + 1) : 0; // Is the last band? If so, go to the first band (AM). Else. Else, next band.
    vfoFreq = band[currentBand].minFreq;
    currentStep = band[currentBand].starStepIndex;

    // Call callback function if exist something to do for the specific  band
    if (band[currentBand].f != NULL)
      (band[currentBand].f)();

    isFreqChanged = true;
    elapsedButton = millis();
  }
```  

### Explicando o uso de sizeof

o sizeof é um operador muito utilizado no C para obter o tamanho em bytes de estruturas de dados, array e tipos primitivos de dados (int, char, long etc). 
Por exemplo: 
long x =  1L;  
int tamanhoX = sizeof x; 

Na maioria das arquiteturas de hardware, é o mesmo que atribuir 4 à variável tamanhoX (explico o porquê do uso adiante).
 
Note no programa foi criado um tipo definido (typedef) para representar as informações de uma banda. Exemplo: 
 
```cpp
typedef struct
{
  char *name;
  uint64_t minFreq; // Min. frequency value for the band (unit 0.01Hz)
  uint64_t maxFreq  // Max. frequency value for the band (unit 0.01Hz)
} Band;
``` 
 
Que tamanho tem o tipo definido Band acima? 
 
Tamanho da variável Band é:  (o tamanho do ponteiro char para nome) + (o tamanho de minFreq) + (o tamanho de maxFreq) 
 
- o tamanho de uma ponteiro é normalmente 4 bytes (para a maioria das arquiteturas de hardware);
- o tamanho de minFreq é 8 bytes (64 bits); e
- o tamanho de maxFreq também é 8 bytes.  
 
Diante disso, o tamanho do tipo definido que foi criado seria: 4 + 8 + 8 = 20 bytes. 
 
#### Por que usar o operador sizeof? 
 
Há várias razões.
 
1.     Dispensa o cálculo do tamanho em bytes da estrutura ou tipo de dados que você estiver usando. Em tempo de compilação, o compilador fará a conversão é trabalhará com o tamanho correto considerando a plataforma de hardware corrente.  
2.     Deixa o código mais fácil de manter. Por exemplo, imagine  que eu queira incluir mais um atributo na minha estrutura conforme mostrado a seguir
```cpp 
typedef struct
{
  char *name;
  uint64_t minFreq; // Min. frequency value for the band (unit 0.01Hz)
  uint64_t maxFreq; // Max. frequency value for the band (unit 0.01Hz)
  uint64_t offset;
} Band;
```

Observe no código acima a inclusão de __offset__. A mudança mostrada no código acima, não demanda a necessidade de recalcular o novo tamanho da estrutura se for usado sizeof. Isto é, sizeof agora retornará 28 bytes.  
 1.     Facilita a migração do código para outras plataformas de microcontroladores. Outros microcontroladores podem usar tamanho padrões de tipos primitivos diferentes do Arduino, por exemplo. Há plataformas que o tipo int é de 32 bits (4 bytes)  e não 16 bits (2 bytes) e há plataformas que usam diferentes tamanhos para ponteiros (dependendo como essas plataformas trabalham com endereçamento de memória).  Com o uso do sizeof, eu não preciso me preocupar com isso neste contexto (tamanho em bytes).
 
#### Qual o objetivo do sizeof no sketch? 
 
A principal razão é a tabela de bandas. Veja o exemplo a seguir: 

```cpp 
// Band database. You can change the band ranges if you need.
// The unit of frequency here is 0.01Hz (1/100 Hz). See Etherkit Library at https://github.com/etherkit/Si5351Arduino
Band band[] = {
    {"MW   ", 50000000LLU, 170000000LLU, 45500000LU},
    {"SW1  ", 700000000LLU, 1000000000LLU, 45500000LU},
    {"SW1  ", 1000000000LLU, 2000000000LLU, 45500000LU},
    {"FM   ", 7600000000LLU, 10800000000LLU, 1075000000LLU},
    {"AIR  ", 10800000000LLU, 13500000000LLU, 1075000000LLU},
    {"VFH  ", 13500000000LLU, 16000000000LLU, 1075000000LLU}}; 
``` 
Note que o array band[] é do tipo Band (o tipo definido que foi criado). 
O  objetivo é saber quantos elementos tem esse array band[]. 
Você agora deve pensar: ora, é só contar. E se fizer isso encontrará 5. 
Naturalmente você poderia fazer isso: 
```cpp 
Band band[5] = {
    {"MW   ", 50000000LLU, 170000000LLU, 45500000LU},
    {"SW1  ", 700000000LLU, 1000000000LLU, 45500000LU},
    {"SW1  ", 1000000000LLU, 2000000000LLU, 45500000LU},
    {"FM   ", 7600000000LLU, 10800000000LLU, 1075000000LLU},
    {"AIR  ", 10800000000LLU, 13500000000LLU, 1075000000LLU},
    {"VFH  ", 13500000000LLU, 16000000000LLU, 1075000000LLU}}; 
```

Bom, isso não estaria errado e muitos programadores fazem assim. Porém, a cada vez que você mudar essa tabela (e isso normalmente ocorre várias vezes), você deverá alterar também a quantidade de elementos do array band e ainda considerar essa nova quantidade em todo o código onde você precisar usá-la.
 
Para evitar esse desconforto e preocupação eu uso a expressão a seguir: 

const int lastBand = (sizeof band / sizeof(Band)) - 1;
 
#### O que ela faz? 
 
Calcula o número de elementos do array band[] e subtrai de 1 porque 4 é o último elemento do array (lembre-se que em C o primeiro elemento é o 0). 

(sizeof band / sizeof(Band)) => Considerando o primeiro exemplo do tipo Band seria: (20 + 20 + 20 + 20 + 20) / 20 = 100 / 20 = 5 ou
considerando o segundo exemplo do tipo definido  Band seria (28 + 28 + 28 + 28 +28) / 28 = 140 / 28 = 5. 

Note que mesmo mudando a estrutura do tipo Band, o resultado do tamanho continuou 5 elementos. Com isso, posso aumentar o número de linhas da tabela (inserir mais bandas), incluir novos atributos (variáveis) e não precisarei fazer nada no resto do código. Em princípio, isso pode parecer complicado, porém, na proporção que os requisitos do sistema ficam mais complexos, essa abordagem pode ajudar.
 
Só mais uma coisa que talvez possa gerar dúvida: 
 
As constantes “MW.  “, “SW1 “, “FM  “ etc.. NÃO fazem parte da estrutura implícita do array do tipo definido Band. A estrutura apenas armazena ponteiros para estas constantes. Em outras palavras, elas não são somadas ao tamanho em bytes da estrutura. Apenas os ponteiros para essas constantes são. 

### Explicando as estruturas Band e Step.

A ideia dessas estruturas é melhorar a manutenibilidade do código com a evolução do projeto. Essas estruturas foram projetadas para oferecer um comportamento distinto para cada banda. Ou seja,  para sintonizar estações de FM, por exemplo, só é necessário 1 dígito para casa decimal, passos entre 50KHz e 500KHz são mais apropriados que passos muito pequenos como 1KHz usado em SW. Já em AM, passos entre 500Hz e 50KHz,  bem como 2 dígitos após a vírgula, creio que funcionam bem . Em SW, é desejável uma precisão melhor, então o passo entre 100Hz e 50KHz, bem como duas casas após a vírgula pode ser mais interessante.  Então vamos a tabela para implementar comportamentos distintos por banda:

O código em C que implementa a tabela pode ser visto a seguir: 

```cpp
// Band database. You can change the band ranges if you need.
// The unit of frequency here is 0.01Hz (1/100 Hz). See Etherkit Library at https://github.com/etherkit/Si5351Arduino
Band band[] = {
    {"MW  ", 50000000LLU, 170000000LLU, 45500000LU, "KHz", 100000.0f, 0, 3, 6, 5, amBroadcast},
    {"SW1 ", 170000000LLU, 1000000000LLU, 45500000LU, "KHz", 100000.0f, 2, 1, 6, 3, amBroadcast},
    {"SW2 ", 1000000000LLU, 2000000000LLU, 45500000LU, "KHz", 100000.0f, 2, 1, 6, 3, amBroadcast},
    {"SW3 ", 2000000000LLU, 3000000000LLU, 45500000LU, "KHz", 100000.0f, 2, 1, 6, 3, amBroadcast},
    {"VHF1", 3000000000LLU, 7600000000LLU, 45500000LU, "KHz", 100000.0f, 2, 1, 7, 3, NULL},
    {"FM  ", 7600000000LLU, 10800000000LLU, 1075000000LLU, "MHz", 100000000.0f, 2, 6, 8, 7, fmBroadcast},
    {"AIR ", 10800000000LLU, 13700000000LLU, 1075000000LLU, "MHz", 100000000.0f, 3, 2, 8, 5, NULL},
    {"VHF2", 13700000000LLU, 14400000000LLU, 1075000000LLU, "MHz", 100000000.0f, 3, 2, 8, 5, NULL},
    {"2M  ", 14400000000LLU, 15000000000LLU, 1075000000LLU, "MHz", 100000000.0f, 3, 2, 8, 5, NULL},
    {"VFH3", 15000000000LLU, 16000000000LLU, 1075000000LLU, "MHz", 100000000.0f, 3, 2, 8, 5, NULL}};
```

Ainda em relação ao código anterior, lembre-se que band[] é do tipo definido Band, que é declarado como se segue: 

```cpp
// Structure for Bands database
typedef struct
{
  char *name;
  uint64_t minFreq; // Min. frequency value for the band (unit 0.01Hz)
  uint64_t maxFreq; // Max. frequency value for the band (unit 0.01Hz)
  long long offset;
  char *unitFreq;         // MHz or KHz
  float divider;          // value that will be the divider of current clock (just to present on display)
  short decimals;         // number of digits after the comma
  short initialStepIndex; // Index to the initial step of incrementing
  short finalStepIndex;   // Index to the final step of incrementing
  short starStepIndex;    // Index to start step of incrementing
  void (*f)(void);        // pointer to the function that handles specific things for the band
} Band;
```

Vamos ao significado de cada variável do tipo definido Band: 

* char *name – É o nome da banda (ponteiro para a “string” que contém o nome da banda);
* uint64_t minFreq  - é a menor frequência possível para a banda;
* uint64_t maxFreq   - é a maior frequência possível para a banda;
* uint64_t offset -  o desconto que tenho que da FI 455KHz para AM e 10.75MHz para FM (e poderia ainda ser diferente para outras bandas que não MW/SW e FM. Creio que isso vai depender da arquitetura do rádio);
* char *unitFreq – É a unidade utilizada para apresentar no display (KHz ou MHz, mas poderia também ser Hz, dependendo do que você queira)
* float divider – É o divisor utilizado para acomodar a frequência no Display e alinhar com a unidade apresentada. Isto é, para os si5351 envio a frequência em uma unidade equivalente a 1/100Hz. Para o Display, ajusto esse valor dependendo da Unidade (KHz ou MHZ). O divisor na realidade converte a unidade exigida para o si5351 para uma unidade compatível com a banda utilizada (KHz ou MHz);
* short decimals – Número de casas decimais que devem ser apresentadas após a vírgula;
* short initialStepIndex – Menor passo de incremento/decremento permitido para a banda. O valor armazenado em initialStepIndex é o índice da tabela (array) step[]); 
* short finalStepIndex – Maior passo de incremento /. Decremento permitido para a banda. . O valor armazenado em finalStepIndex é o índice da tabela (array) step[])
* short starStepIndex – E o passo padrão da banda. Quando a banda for selecionada, o passo que será usando está definido em starStepIndex. Lambrando que o valor armazenado em starStepIndex é o índice da tabela (array) step[]) 
* void (*f)(void) - Ponteiro para uma função que será executada quando uma determinada banda for selecionada. 

Agora voltando a tabela band, observe as informações da primeira banda (índice 0, “MW”): 

{"MW  ", 50000000LLU, 170000000LLU, 45500000LU, "KHz", 100000.0f, 0, 3, 6, 5, amBroadcast},

* char *name – “MW   “;
* uint64_t minFreq  - 50000000LLU;
* uint64_t maxFreq   - 170000000LLU;
* uint64_t offset - 45500000LU;
* char *unitFreq – " KHz";
* long divider – 100000.0f;
* short decimals – 0
* short initialStepIndex – 3 -> (1KHz) Ver tabela step; 
* short finalStepIndex – 6 ->  (50KHz) Ver tabela step;
* short starStepIndex – 5 -> (10KHz) ver tabela step;
* void (*f)(void) - amBroadcast.

```cpp
// Steps database. You can change the Steps and numbers of steps here if you need.
Step step[] = {
    {"10Hz  ", 1000},     // index 0
    {"100Hz ", 10000},    // 1
    {"500Hz ", 50000},	// 2
    {"1KHz  ", 100000},	// 3
    {"5KHz  ", 500000},	// 4
    {"10KHz  ",1000000},	// 5
    {"50KHz ", 5000000},	// 6
    {"100KHz", 10000000},	// 7
    {"500KHz", 50000000}}; // 8
```

Vamos agora ao uso dessas tabelas/estruturas no programa: 

Quando a Banda é alterada: 

```cpp
  if (digitalRead(BUTTON_BAND) == HIGH && (millis() - elapsedButton) > MIN_ELAPSED_TIME)
  {
    currentBand = (currentBand < lastBand) ? (currentBand + 1) : 0; // Is the last band? If so, go to the first band (AM). Else. Else, next band.
    vfoFreq = band[currentBand].minFreq;
    currentStep = band[currentBand].starStepIndex;

    // Call callback function if exist something to do for the specific band
    if (band[currentBand].f != NULL)
      (band[currentBand].f)();

    isFreqChanged = true;
    elapsedButton = millis();
  }
```

Note o código
currentStep = band[currentBand].starStepIndex;

o código acima faz o step na informação guardada em startStepIndex.

Mudança do Step: 

```cpp 
else if (digitalRead(BUTTON_STEP) == HIGH && (millis() - elapsedButton) > MIN_ELAPSED_TIME)
  {
   if (currentClock == 0)                                               // Is VFO
     currentStep = (currentStep < band[currentBand].finalStepIndex) ? (currentStep + 1) : band[currentBand].initialStepIndex; // Increment the step or go back to the first
    else                                                                 // Is BFO
    currentStep = (currentStep < lastStepBFO) ? (currentStep + 1) : 0;
    isFreqChanged = false;
    clearDisplay = true;
    elapsedButton = millis();
  }
 ```

Na mudança de step, verifico os limites permitidos para o step. Onserve o código
  currentStep = (currentStep < band[currentBand].finalStepIndex) ? (currentStep + 1) : band[currentBand].initialStepIndex; 

Neste código, testo se o passo corrente (currentStep) é menor que o máximo permitido para a banda “band[currentBand].finalStepIndex”. Caso afirmativo, incremento 1 para ir para o próximo passo (currentStep + 1); caso contrário, vou para o primeiro passo permitido para a banda “band[currentBand].initialStepIndex”.

Na função Display, também uso esta tabela. Observe: 
```cpp
void displayDial()
{
  double vfo = (double)vfoFreq / band[currentBand].divider;
  double bfo = (double)bfoFreq / 100000.0f;
  String mainFreq;
  String secoundFreq;
  String staticFreq;
  String dinamicFreq;

  // Change the display behaviour depending on who is controlled, BFO or BFO.
  if (currentClock == 0)
  { // If the encoder is controlling the VFO
    mainFreq = String(vfo, band[currentBand].decimals);
    mainFreq.concat(band[currentBand].unitFreq);
    secoundFreq = String(bfo, 2);
    staticFreq = "BFO";
    dinamicFreq = "VFO";
  }
  else // encoder is controlling the VFO
  {
    mainFreq = String(bfo, 2);
    secoundFreq = String(vfo, band[currentBand].decimals);
    secoundFreq.concat(band[currentBand].unitFreq);
    staticFreq = "VFO";
    dinamicFreq = "BFO";
  }

...
```

No código
double vfo = (double)vfoFreq / band[currentBand].divider;

é feita a divisão pelo valor de band[currentBand].divider. 

Note também que se for o VFO a principal informação, uso o número de casas decimais adequadas para a banda. Veja o código: 

mainFreq = String(vfo, band[currentBand].decimals);

e também apresento a unidade de frequência selecionada para a banda. Veja: 

mainFreq.concat(band[currentBand].unitFreq);

obs: concat é um método da classe string que junta duas strings.  Dessa forma a frequência e a unidade ficarão na mesma string.

Por fim, foi apresentado os elementos do uso das tabelas band[] e step[]. É possível que o leitor tenha achado a solução um pouco mais complexa de entender no início. __PORÉM__ imagine o seguinte: 

1. Se você tivesse que  implementar o comportamento de cada banda com __IF e ELSE ou CASE__ no código, como ficaria esse código? Mais legível? Para uma ou duas  Bandas provavelmente sim, para várias bandas, certamente não. 
2. Se você precisar retirar uma banda do sistema é só excluir a linha da tabela referente a banda. Não será preciso fazer mais nada no código. Só compilar e aquela banda não fará mais parte do sistema. E como seria se você tivesse implementado a banda no código? Procuraria o __IF, ELSE ou CASE__ relacionados e removeria o código. Mas será que isso não é mais trabalhoso e sujeito a incluir erros no código?   
3. Na mesma analogia com o item anterior, se você precisar adicionar mais uma banda (subdividindo as outras), tudo que é preciso fazer é adicionar mais uma linha com as informações da nova banda na tabela band[]. Como seria usando codificação como __IF, ELSE ou CASE__? Mais fácil?    

### Explicando como o Encoder está codificado 

Não há uso de interrupção nem uma biblioteca específica para trabalhar no encoder no código deste projeto. Simplesmente é feita a leitura nos pinos do encoder. 

O primeiro passo é informar ao Arduino que os pinos do Encoder são somente de ENTRADA (INPUT)   (Função setup() )

```cpp
pinMode(ENCODER_PIN_A, INPUT);
pinMode(ENCODER_PIN_B, INPUT);
```

Depois declaro as variáveis de controle do encoder (incluindo o tempo mínimo para a processar a próxima ação)

```cpp
long elapsedTimeEncoder = millis();

// Encoder variable control
unsigned char encoder_pin_a;
unsigned char encoder_prev = 0;
unsigned char encoder_pin_b;
```

O tipo unsigned char é na realidade um número inteiro, não sinalizado de 8 bits. Ele admite valores entre 0 e 255. No caso do encoder, terão valores 0 (nível lógico baixo) ou diferente de 0 (nível lógico alto). Poderia ser um int. A questão aqui é de economia de memória e, provavelmente, redução do número de cíclos de máquina. 

A variável encoder_prev armazena a última ação do encoder. Dessa forma, na ação seguinte do encoder é possível usar o valor da ação anterior para poder fazer comparação e agir de forma adequada;

Na função  loop(), o processo inicia checando se já ocorreu mais de 5 milisegundos após a última ação do encoder.  Caso não tenha ocorrido mais de 5 milisegundos, não processa a ação do encoder. Isso é útil para eliminar efeitos indesejáveis causados pelo mal contato das placas metálicas do encoder (ver Debounce);

```cpp
if ((millis() - elapsedTimeEncoder) > 5)
{
encoder_pin_a = digitalRead(ENCODER_PIN_A);
encoder_pin_b = digitalRead(ENCODER_PIN_B);
if ((!encoder_pin_a) && (encoder_prev)) // has ENCODER_PIN_A gone from high to low?
{ // if so, check ENCODER_PIN_B. It is high then clockwise (1) else counter-clockwise (-1)
changeFreq(((encoder_pin_b) ? 1 : -1));
}
encoder_prev = encoder_pin_a;
elapsedTimeEncoder = millis(); // keep elapsedTimeEncoder updated
}
```

caso o tempo decorrido entre a última ação do encoder e o tempo atual for maior que 5 milissegundos, então os dois pinos do encoder são lidos.

Se o PINO A (encoder_pin_a) estiver em nível lógico baixo (0) e o encoder_prev (ação anterior deste pino) estiver em nível lógico alto (1), então é porque houve mudança no status do encoder (houve giro);
Lembrando que   __!encoder_pin_a__ poderá ter os seguintes resultados: se encoder_pin_a for 0, o resultado será 1 (verdadeiro); se  encoder_pin_a for 1, o resultado será 0 (falso); 

Se a expressão __if ((!encoder_pin_a) && (encoder_prev))__  for verdadeira (houve giro no encoder). Agora vamos determinar qual o sentido (horário ou anti-horário). Quem vai dizer isso é estado do encoder_pin_b.  
Se encoder_pin_b estiver em nível lógico alto (1), então é sentido horário. Caso contrário, nível lógico baixo (0), é anti-horário. 
A linguagem C permite uma atribuição condicional na forma apresentada no exemplo a seguir:  X = ( A > B)? 1:-1); Neste exemplo, X recebe 1 se A for maior que B; caso contrário, recebe -1;
Observe a expressão dentro da chamada da função changeFreq(): 
((encoder_pin_b) ? 1 : -1)
A função changeFreq() recebe dois possíveis valores como parâmero: 1 para incrementar (adicionar o step) a frequência (sentido horário do encoder); e -1 para decrementar (sentido anti-horário).  
se encoder_pin_b for 1 (ou qualquer valor diferente de 0), então changeFreq() será chamada com o valor 1 (equivalente à chamada changeFreq(1)). Caso contrário, encoder_pin_b for igual a 0 changeFreq() será chamada com o valor -1 (equivalente à chamada changeFreq(-1)).

Note que dentro do bloco atendida pela condição do encoder [if ((millis() - elapsedTimeEncoder) > 5)]  , eu armazeno a ação corrente na variável encoder_prev. E também atualizo o tempo em elapsedTimeEncoder. 
encoder_prev = encoder_pin_a;
elapsedTimeEncoder = millis(); // keep elapsedTimeEncoder updated
com isso, após 5 milissegundos, poderei ler os pinos do encoder novamente e verificar se ouve uma ação de giro. 

## Vídeos 

- [VFO and BFO project test with an inexpencive radio based on CD2003GP](https://youtu.be/_KgBc6vYWLg)
- [Versão preliminar do VFO controlado por Celular via Bluetooth](https://youtu.be/D-7cL-VDCBg)

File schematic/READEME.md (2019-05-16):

# The Arduino and components wire up.

This schematic was made by using the [Fritzing Software](http://fritzing.org/home/)">

## Schematic

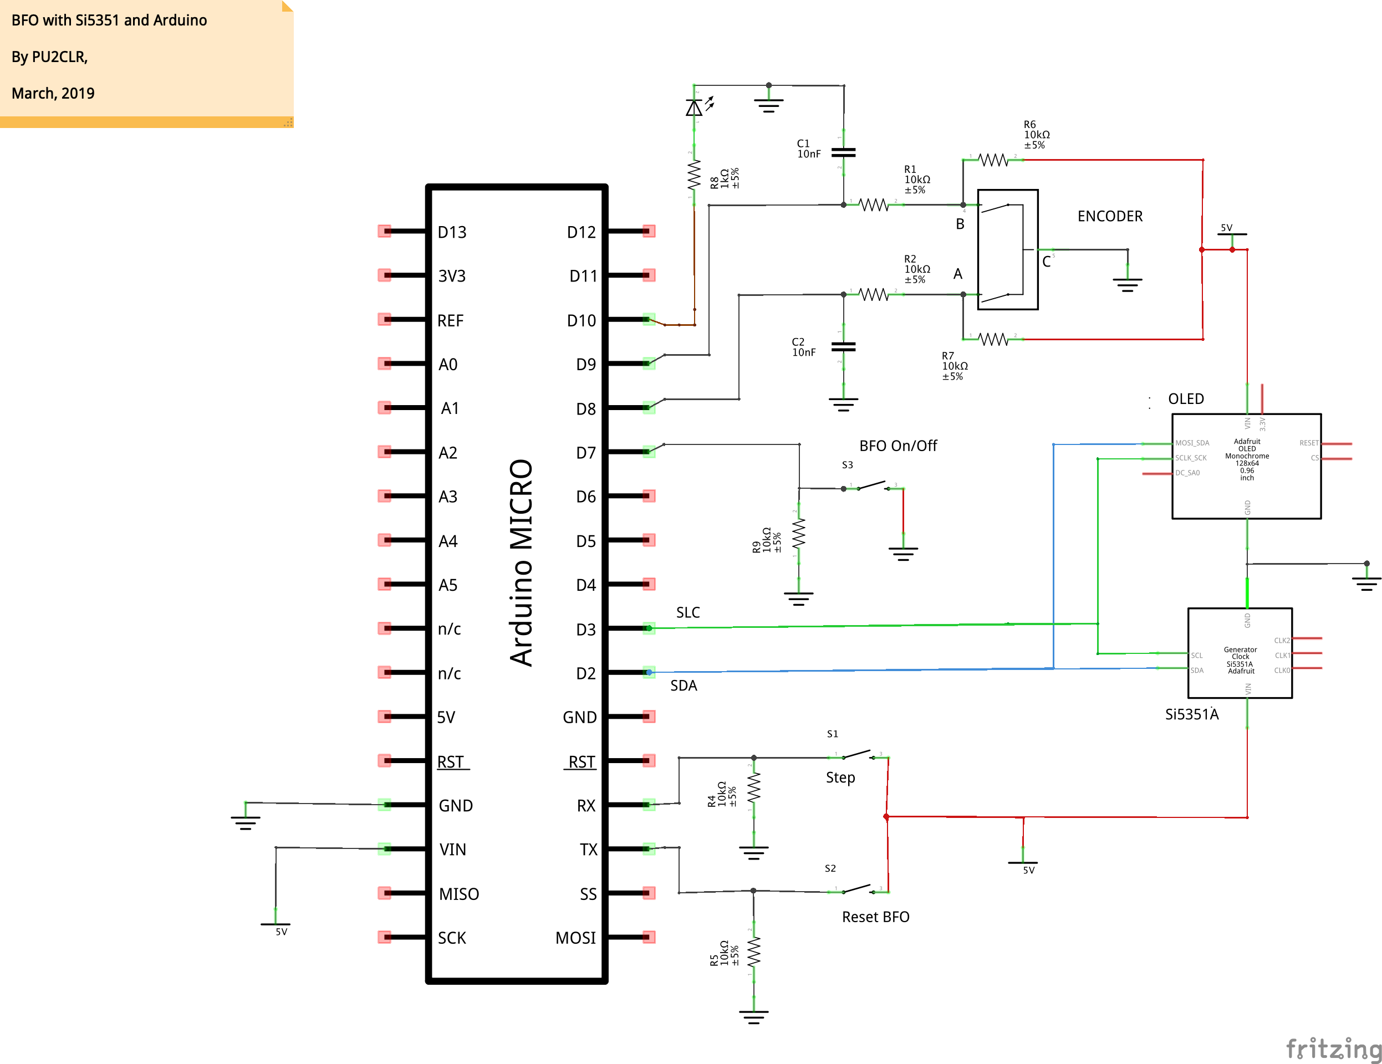
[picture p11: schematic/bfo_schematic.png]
BFO schematic
 

### Si5351A

The __Si5351A__ is connected to D2 (SDA) and  D3 (SCL).

### OLED Display SSD1306 - 128 x 64/0.96

The __OLED__ is connected to D2 (SDA) and  D3 (SCL). Yes, the same Si5351A connections.

### Encoder

Connect Arduino __D8__ and __D9__ pins to the __Encoder__ pin __A__ and pin __B__ respectively.

### Push Button Step

Connect Arduino __D1/Tx__ pin to the __Step__ push button (S1). 

### Reset VFO

Connect Arduino __D0__ pin to the __Reset BFO__ push button (S2).

### BFO On/OFF 

Connect the Arduino pin __D7__ to the BFO On/Off push button  (S3).

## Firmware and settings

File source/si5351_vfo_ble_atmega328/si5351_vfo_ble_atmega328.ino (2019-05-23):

/*
  Program to control the "Adafruit Si5351A Clock Generator" or similar via Arduino.
  This program control the frequencies of two clocks (CLK) output of the Si5351A
  The CLK 0 can be used as a VFO (535KHz to 160MHz)
  The CLK 1 can be used as a BFO (400KHz to 500KHz)

  Testing Bluetooth BLE connection and control
  
  See on https://github.com/etherkit/Si5351Arduino  and know how to calibrate your Si5351
  See also the example Etherkit/si5251_calibration
  Author: Ricardo Lima Caratti (PU2CLR) -   April, 2019
*/

#include <si5351.h>
#include <Wire.h>
#include <SSD1306Ascii.h>
#include <SSD1306AsciiAvrI2c.h>
#include <SoftwareSerial.h>

#define BLUETOOTH_TX 11
#define BLUETOOTH_RX 10

// Initiate BLE (HM10) Instance
SoftwareSerial ble(BLUETOOTH_TX, BLUETOOTH_RX);

// Enconder PINs
#define ENCODER_PIN_A 3 // 
#define ENCODER_PIN_B 2 // 

// OLED Diaplay constants
#define I2C_ADDRESS 0x3C
#define RST_PIN -1 // Define proper RST_PIN if required.

// Change this value below  (CORRECTION_FACTOR) to 0 if you do not know the correction factor of your Si5351A.
#define CORRECTION_FACTOR 70000 // See how to calibrate your Si5351A (0 if you do not want).

#define BUTTON_STEP    4    // Control the frequency increment and decrement
#define BUTTON_BAND    5    // Controls the band
#define BUTTON_VFO_BFO 6    // Switch VFO to BFO

// BFO range for this project is 400KHz to 500KHz. The central frequency is 455KHz.
#define MAX_BFO 45800000LU    // BFO maximum frequency
#define CENTER_BFO 45500000LU // BFO centeral frequency
#define MIN_BFO 45200000LU    // BFO minimum frequency

#define AM_LED 8       // Indicate that the radio is working in AM mode
#define FM_LED 9       // Indicate that the radio is working in FM mode

#define STATUS_LED 13 // Arduino status LED Pin 10
#define STATUSLED(ON_OFF) digitalWrite(STATUS_LED, ON_OFF)
#define MIN_ELAPSED_TIME 300

// OLED - Declaration for a SSD1306 display connected to I2C (SDA, SCL pins)
SSD1306AsciiAvrI2c display;

// The Si5351 instance.
Si5351 si5351;

// Callback functions declarations
// Depending on the selected band, you may want to perform specific actions
// The functions declared below will do something for AM and FM BAND. See implementation later.
// You can implement callback function for other bands
void amBroadcast();      // See implementation later.
void fmBroadcast();      // See implementation later.
void defultFinishBand(); // 

// Structure for Bands database
typedef struct
{
  char *name;
  uint64_t minFreq;       // Min. frequency value for the band (unit 0.01Hz)
  uint64_t maxFreq;       // Max. frequency value for the band (unit 0.01Hz)
  uint64_t lastFreq;      // Store the current frequency before change to other band (starts with minFreq value)
  long long offset;
  char *unitFreq;         // MHz or KHz
  float divider;          // value that will be the divider of current clock (just to present on display)
  short decimals;         // number of digits after the comma
  short initialStepIndex; // Index to the initial step of incrementing
  short finalStepIndex;   // Index to the final step of incrementing
  short lastStepIndex;    // Index to the last step used (initial index value same index defult)
  void (*doSmth)(void);   // pointer to the function that will handle specific things for the band immediately after the band is selected
 } Band;

// Band database. You can change the band ranges if you need.
// The unit of frequency here is 0.01Hz (1/100 Hz). See Etherkit Library at https://github.com/etherkit/Si5351Arduino
 Band band[] = {
     {"MW  ", 50000000LLU, 170000000LLU, 50000000LLU, 45500000LU, "KHz", 100000.0f, 0, 3, 6, 5, amBroadcast},
     {"SW1 ", 170000000LLU, 1000000000LLU, 170000000LLU, 45500000LU, "KHz", 100000.0f, 2, 1, 6, 3, amBroadcast},
     {"SW2 ", 1000000000LLU, 2000000000LLU, 1000000000LLU, 45500000LU, "KHz", 100000.0f, 2, 1, 6, 3, amBroadcast},
     {"SW3 ", 2000000000LLU, 3000000000LLU, 2000000000LLU, 45500000LU, "KHz", 100000.0f, 2, 1, 6, 3, amBroadcast},
     {"VHF1", 3000000000LLU, 7600000000LLU, 3000000000LLU, 45500000LU, "KHz", 100000.0f, 2, 1, 7, 3, defultFinishBand},
     {"FM  ", 8600000000LLU, 10800000000LLU, 8600000000LLU, 1070000000LLU, "MHz", 100000000.0f, 2, 5, 8, 7, fmBroadcast},
     {"AIR ", 10800000000LLU, 13700000000LLU, 10800000000LLU, 1070000000LLU, "MHz", 100000000.0f, 3, 2, 8, 5, defultFinishBand},
     {"VHF2", 13700000000LLU, 14400000000LLU, 13700000000LLU, 1070000000LLU, "MHz", 100000000.0f, 3, 2, 8, 5, defultFinishBand},
     {"2M  ", 14400000000LLU, 15000000000LLU, 14400000000LLU, 1070000000LLU, "MHz", 100000000.0f, 3, 2, 8, 5, defultFinishBand},
     {"VFH3", 15000000000LLU, 16000000000LLU, 15000000000LLU, 1070000000LLU, "MHz", 100000000.0f, 3, 2, 8, 5, defultFinishBand}};
 // Calculate the last element position (index) of the array band
 const int lastBand = (sizeof band / sizeof(Band)) - 1; // For this case will be 26.
 short currentBand = 0;                                 // First band. For this case, AM is the current band.

 // Struct for step database
 typedef struct
 {
   char *name; // step label: 50Hz, 100Hz, 500Hz, 1KHz, 5KHz, 10KHz and 500KHz
   long value; // Frequency value (unit 0.01Hz See documentation) to increment or decrement
} Step;

// Steps database. You can change the Steps and numbers of steps here if you need.
Step step[] = {
    {"10Hz  ", 1000},
    {"100Hz ", 10000},
    {"500Hz ", 50000},
    {"1KHz  ", 100000},
    {"5KHz  ", 500000},
    {"10KHz  ", 1000000},
    {"50KHz ", 5000000},
    {"100KHz", 10000000},
    {"500KHz", 50000000}};

// Calculate the index of last position of step[] array (in this case will be 8)
const short lastStepVFO = (sizeof step / sizeof(Step)) - 1; // index for max increment / decrement for VFO
short lastStepBFO = 3;                                      // index for max. increment / decrement for BFO. In this case will be is 1KHz
uint64_t bfoFreq = CENTER_BFO;                              // 455 KHz for this project

boolean isFreqChanged = true;
boolean clearDisplay = false;

// LW/MW is the default band
uint64_t vfoFreq = band[currentBand].minFreq;        // VFO starts on MW
short currentStep = band[currentBand].lastStepIndex; // Step starts on default MW

// VFO is the Si5351A CLK0
// BFO is the Si5351A CLK1
short currentClock = 0; // If 0, then VFO will be controlled else the BFO will be

long elapsedButton = millis(); // will control the minimum time to process an interrupt action
long elapsedTimeEncoder = millis();

// Encoder variable control
unsigned char encoder_pin_a;
unsigned char encoder_prev = 0;
unsigned char encoder_pin_b;

void setup()
{
  // LED Pin
  pinMode(STATUS_LED, OUTPUT);
  pinMode(AM_LED, OUTPUT);
  pinMode(FM_LED, OUTPUT);

  // Encoder pins
  pinMode(ENCODER_PIN_A, INPUT);
  pinMode(ENCODER_PIN_B, INPUT);
  // Si5351 contrtolers pins
  pinMode(BUTTON_BAND, INPUT);
  pinMode(BUTTON_STEP, INPUT);
  pinMode(BUTTON_VFO_BFO, INPUT);

  // Start bluetooth serial at 9600 bps.
  Serial.begin(9600);
  ble.begin(9600);

  // The sistem is alive
  blinkLed(STATUS_LED, 100);

  STATUSLED(LOW);
  // Initiating the OLED Display
  display.begin(&Adafruit128x64, I2C_ADDRESS);
  display.setFont(System5x7);
  display.set2X();
  display.clear();
  display.print("\n PU2CLR");
  delay(3000);
  display.clear();
  displayDial();
  // Initiating the Signal Generator (si5351)
  si5351.init(SI5351_CRYSTAL_LOAD_8PF, 0, 0);
  // Adjusting the frequency (see how to calibrate the Si5351 - example si5351_calibration.ino)
  si5351.set_correction(CORRECTION_FACTOR, SI5351_PLL_INPUT_XO);
  si5351.set_pll(SI5351_PLL_FIXED, SI5351_PLLA);
  si5351.set_freq(vfoFreq - band[currentBand].offset, SI5351_CLK0); // Start CLK0 (VFO)

  // To see later
  // si5351.set_freq(bfoFreq, SI5351_CLK1);
  si5351.output_enable(SI5351_CLK1, 0);
  si5351.output_enable(SI5351_CLK2, 0);

  si5351.update_status();
  // Show the initial system information

  // Set defult Band (go to MW)
  changeBand(0);

  delay(100);
}


// Blink the STATUS LED
void blinkLed(int pinLed, int blinkDelay)
{
  for (int i = 0; i < 3; i++)
  {
    STATUSLED(HIGH);
    delay(blinkDelay);
    STATUSLED(LOW);
    delay(blinkDelay);
  }
}

// Show Signal Generator Information
// Verificar setCursor() em https://github.com/greiman/SSD1306Ascii/issues/53
void displayDial()
{
  double vfo = (double)vfoFreq / band[currentBand].divider;
  double bfo = (double)bfoFreq / 100000.0f;
  String mainFreq;
  String secoundFreq;
  String staticFreq;
  String dinamicFreq;
  String strAux;

  // Change the display behaviour depending on who is controlled, BFO or BFO.
  if (currentClock == 0)
  { // If the encoder is controlling the VFO
    mainFreq = String(vfo, band[currentBand].decimals);
    secoundFreq = String(bfo, 2);
    staticFreq = "BFO";
    dinamicFreq = "VFO";
  }
  else // encoder is controlling the VFO
  {
    mainFreq = String(bfo, 2);
    secoundFreq = String(vfo, band[currentBand].decimals);
    secoundFreq.concat(band[currentBand].unitFreq);
    staticFreq = "VFO";
    dinamicFreq = "BFO";
  }

  // Show Band information
  display.setCursor(0, 0);
  display.set1X();
  strAux = String(band[currentBand].name);
  display.print(strAux);
  
  strAux = band[currentBand].unitFreq;

  ble.print(mainFreq + " " + strAux + "\n");
  
  display.setCursor(29, 0);
  display.print(strAux);
  display.setCursor(55, 0);
  display.print(dinamicFreq);
  display.setCursor(80, 0);
  strAux = "S:" + String(step[currentStep].name);
  display.print(strAux);

  // Show main frequency (VFO or BFO)
  display.set2X();
  display.setCursor(0, 3);

  strAux = mainFreq + "     ";
  display.print(strAux);

  display.setCursor(0, 7);
  display.set1X();
  // Show VFO or BFO frequency
  strAux = staticFreq + ": " + secoundFreq;
  display.print(strAux);
}

// Change the frequency (increment or decrement)
// direction parameter is 1 (clockwise) or -1 (counter-clockwise)
void changeFreq(int direction)
{
  if (currentClock == 0)
  { // Check who will be chenged (VFO or BFO)
    vfoFreq += step[currentStep].value * direction;
    // Check the VFO limits
    if (vfoFreq > band[currentBand].maxFreq) // Max. VFO frequency for the current band
    {
      vfoFreq = band[currentBand].minFreq; // Go to min. frequency of the range
      blinkLed(STATUS_LED, 50);            // Alert the user that the range is over
    }
    else if (vfoFreq < band[currentBand].minFreq) // Min. VFO frequency for the band
    {
      vfoFreq = band[currentBand].maxFreq; // Go to max. frequency of the range
      blinkLed(STATUS_LED, 50);            // Alert the user that the range is over
    }
  }
  else
  {
    bfoFreq += step[currentStep].value * direction; // currentStep * direction;
    // Check the BFO limits
    if (bfoFreq > MAX_BFO || bfoFreq < MIN_BFO) // BFO goes to center if it is out of the limits
    {
      bfoFreq = CENTER_BFO;     // Go to center
      blinkLed(STATUS_LED, 50); // Alert the user that the range is over
    }
  }
  isFreqChanged = true;
}

// It is executed when a new band is selected.
void changeBand(short idxBand)
{
  // Save current status of the current band
  band[currentBand].lastStepIndex = currentStep;
  band[currentBand].lastFreq = vfoFreq;

  // Now change the current band
  currentBand = idxBand;

  // Get back last information stored for this band.
  vfoFreq = band[idxBand].lastFreq;
  currentStep = band[idxBand].lastStepIndex;

  // Call callback function if exist something to do for this band (current band)
  if (band[idxBand].doSmth != NULL)
    (band[idxBand].doSmth)();

  isFreqChanged = true;
}

// Callback implementation

// Doing something spefict for MW band
void amBroadcast()
{
  digitalWrite(AM_LED, HIGH); // Turn ON the AM LED
  digitalWrite(FM_LED, LOW);
  // DO SOMETHING ELSE
}

// Doing something spefict for FM
void fmBroadcast()
{
  digitalWrite(AM_LED, LOW);
  digitalWrite(FM_LED, HIGH); // Turn ON the FM LED
  // DO SOMETHING ELSE
}

// Defaul action
// It is another callback function that can be called when a specific band is selected
void defultFinishBand()
{
  digitalWrite(FM_LED, LOW); // Turno the FM LED OFF
  digitalWrite(AM_LED, LOW); // Turno the AM LED OFF
  // DO SOMETHING ELSE
}

// Bluetooth communication

// Send VFO/BFO database to mobile device
void sendDatabase()
{
  // Building  JSON string  =>  {"band":["MW  ", "SW2  "...]}
  String jsonBand = "#B{\"bands\":[";  // #J Means that a Json information will be processed by the SmartPhone
  short i;

  // Building Json string

  // Bands table
  for (i = 0; i < lastBand; i++)
  {
    jsonBand.concat("{\"name\":\"");
    jsonBand.concat(band[i].name);
    jsonBand.concat("\", \"unt\":\"");
    jsonBand.concat(band[i].unitFreq);
    jsonBand.concat("\"},");
  }
  jsonBand.concat("{\"name\":\"");
  jsonBand.concat(band[i].name);
  jsonBand.concat("\", \"unt\":\"");
  jsonBand.concat(band[i].unitFreq);
  jsonBand.concat("\"}]}\n"); // '\n' means the and of the message
  ble.print(jsonBand);
  Serial.println(jsonBand);

  // Steps table
  jsonBand = "#S{\"steps\":[";;
  for (i = 0; i < lastStepVFO; i++) {
    jsonBand.concat("{\"name\":\"");
    jsonBand.concat(step[i].name);
    jsonBand.concat("\",\"value\":");
    jsonBand.concat(step[i].value);
    jsonBand.concat("},");
  }
  jsonBand.concat("{\"name\":\"");
  jsonBand.concat(step[i].name);
  jsonBand.concat("\",\"value\":");
  jsonBand.concat(step[i].value);
  jsonBand.concat("}]}\n");

  Serial.println(jsonBand);
  ble.print(jsonBand);
}

// Process a long message sent by the Smartphone (message started with '#')
void processMessage()
{
  String buffer = ble.readString();
  Serial.println(buffer);
  // TO DO
}


// main loop
void loop()
{
  // Enconder action can be processed after 5 milisecounds
  if ((millis() - elapsedTimeEncoder) > 5)
  {
    encoder_pin_a = digitalRead(ENCODER_PIN_A);
    encoder_pin_b = digitalRead(ENCODER_PIN_B);
    if ((!encoder_pin_a) && (encoder_prev)) // has ENCODER_PIN_A gone from high to low?
    {                                       // if so,  check ENCODER_PIN_B. It is high then clockwise (1) else counter-clockwise (-1)
      changeFreq(((encoder_pin_b) ? 1 : -1));
    }
    encoder_prev = encoder_pin_a;
    elapsedTimeEncoder = millis(); // keep elapsedTimeEncoder updated
  }
  // check if some action changed the frequency
  if (isFreqChanged)
  {
    if (currentClock == 0)
    {
      si5351.set_freq(vfoFreq - band[currentBand].offset, SI5351_CLK0);
    }
    else
    {
      si5351.set_freq(bfoFreq, SI5351_CLK1);
    }
    isFreqChanged = false;
    displayDial();
  } //  end encoder control

  // check if some button is pressed
  if (digitalRead(BUTTON_BAND) == HIGH && (millis() - elapsedButton) > MIN_ELAPSED_TIME)
  {
    changeBand( (currentBand < lastBand)? (currentBand + 1) : 0 ); 
    elapsedButton = millis();
  }
  else if (digitalRead(BUTTON_STEP) == HIGH && (millis() - elapsedButton) > MIN_ELAPSED_TIME)
  {
    if (currentClock == 0)                                                                                                     // Is VFO
      currentStep = (currentStep < band[currentBand].finalStepIndex) ? (currentStep + 1) : band[currentBand].initialStepIndex; // Increment the step or go back to the first
    else                                                                                                                       // Is BFO
      currentStep = (currentStep < lastStepBFO) ? (currentStep + 1) : 0;
    clearDisplay = true;
    elapsedButton = millis();
  }
  else if (digitalRead(BUTTON_VFO_BFO) && (millis() - elapsedButton) > MIN_ELAPSED_TIME == HIGH)
  {
    currentClock = !currentClock;
    currentStep = (currentClock == 0) ? band[currentBand].lastStepIndex : 0;
    clearDisplay = true;
    elapsedButton = millis();
  } // end button control

  // Check if mobile device sent something
  if (ble.available())
  {
    // Just testing. Will be improved
    char c = ble.read(); // Get message from mobile device (Smartphone)
    switch (c)
    {
    case '+':
      currentClock = 0;
      changeFreq(+1); // Increment VFO
      break;
    case '-':
      currentClock = 0;
      changeFreq(-1); // Decrement VFO
      break;
    case '>':
      currentClock = 1;
      currentStep = 0;
      changeFreq(+1); // Increment BFO
      break;
    case '<':
      currentClock = 1;
      currentStep = 0;
      changeFreq(-1); // Decrement BFO
      break;
    case 'd':
      sendDatabase(); // Send VFO/BFO information (Bands, Steps and current status) to mobile device
      break;
    case 'm':
      changeBand(0);   // Band MW (AM)
      break;
    case 'f':
      changeBand(5);  // Band FM
      break;
    case '#':
      // Follow the protocol
      processMessage();
      break;
    default:
      break;
    }
  } // end bluetooth control

  // Check if it is necessary to refresh the display
  if (clearDisplay)
  {
    display.clear();
    displayDial();
    clearDisplay = false;
  }

} // end loop

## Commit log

2019-05-16 Secound Commit
    [bfo_schematic.fzz, coupling_01.fzz, coupling_02.fzz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]
2019-05-16 Fixing text
    [vfobfo_ir_schematic_atmega328.fzz, vfobfo_schematic_atmega328.fzz]
2019-05-17 Arduino Sketch
